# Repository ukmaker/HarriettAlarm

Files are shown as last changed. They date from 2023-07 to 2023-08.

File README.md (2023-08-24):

-- An STM32 BlackPill based alarm clock.

Called the Harriett clock because that's the name of my personal trainer.
Sometimes I forget to set the alarm on my phone or otherwise botch getting up.
This is embarrassing, rude and annoying :-(
So I invented the Harriett alarm so that it was obvious even to an old short-sighted
person like me what is happening the next day:

  * Picture of me tucked up in bed => I get to sleep in. No alarm set.
  * Picture of me with a phone to my ear => Work! Alarm!
  * Picture of me lifting weights with Harriett counting the reps(*) => Training day! Alarm!

(*) We always disagree on the number of reps I've done.

With added special features like
 * you can set the time (!)
 * each alarm can have a different tone and volume (!!)

Originally this was built to use a DFRobot MP3 player, and there was a selection of 
eight alarm tones to choose from. However the module consumes so much power at start-up
(and takes so long to start) that it was causing problems. So I replaced it with a simple
set of beeping tones using a Timer and PWM. The code (and the hardware design) for the MP3 
player is still in place however, should you wish to actually build this thing.

The rest of the hardware involves a Waveshare epaper screen, some buttons
and a 3D printed box.

In order to help with debugging I also embedded my Forth virtual machine, which communicates
over a serial port. This was surprisingly useful and not at all silly and done for the sake of it.
Honest.

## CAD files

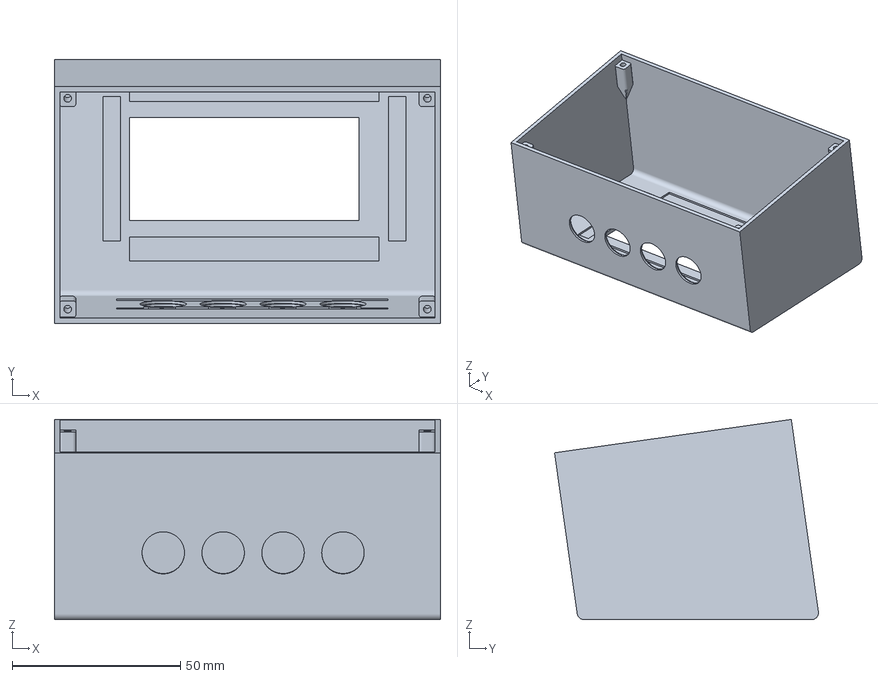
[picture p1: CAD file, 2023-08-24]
V1.0/OpenSCAD/HarriettBox2.3mf
114.6 x 78.4 x 59.4 mm

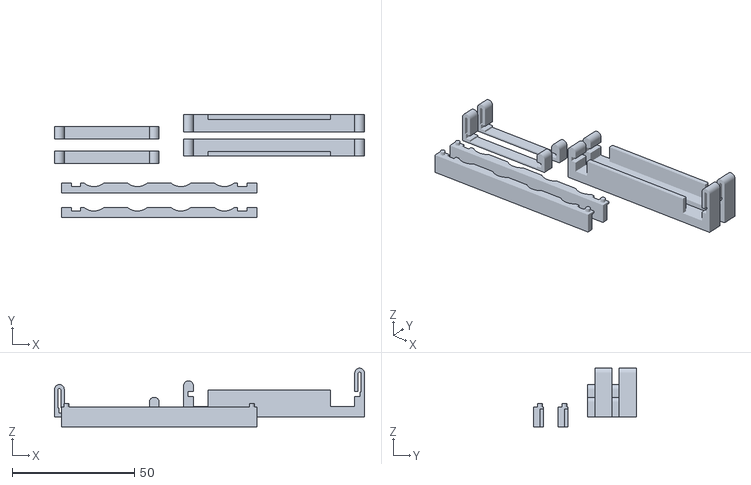
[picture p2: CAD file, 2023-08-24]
V1.0/OpenSCAD/HarriettBox2-Clips.stl
126.8 x 42.0 x 24.0

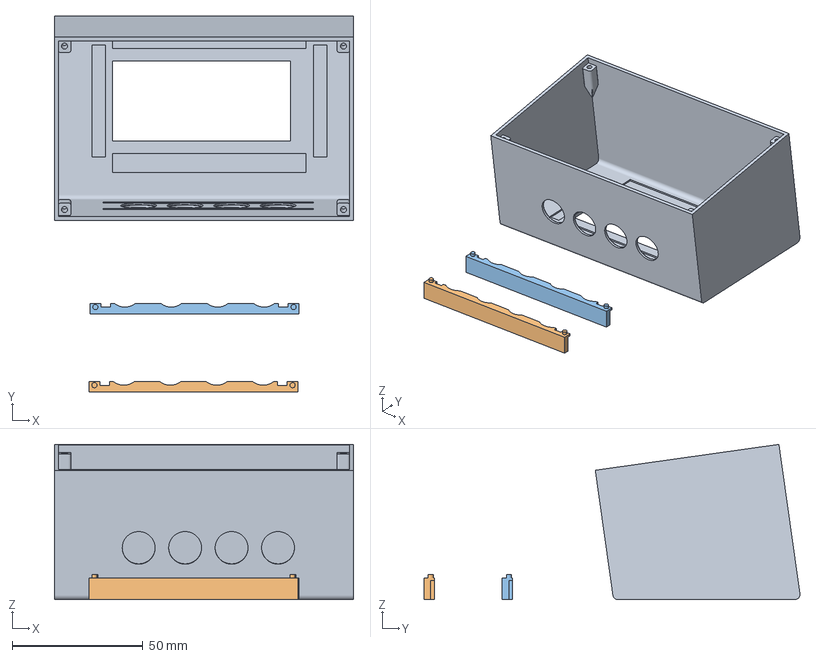
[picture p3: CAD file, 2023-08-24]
V1.0/OpenSCAD/HarriettBox2-PCBClips.3mf
114.6 x 143.9 x 59.4 mm
HarriettBox2.stl_1
HarriettBox2.stl_2
HarriettBox2.stl_3

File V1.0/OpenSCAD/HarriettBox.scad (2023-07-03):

use <ukmaker_openscad_lib/Generics.scad>
use <ukmaker_openscad_lib/Standoffs.scad>
use <ukmaker_openscad_lib/Batteries.scad>
use <ukmaker_openscad_lib/Waveshare.scad>
use <ukmaker_openscad_lib/Boxes.scad>
use <ukmaker_openscad_lib/Speakers.scad>
use <ukmaker_openscad_lib/GreenProtoBoards.scad>

include <NopSCADlib/utils/core/core.scad>


include <NopSCADlib/vitamins/buttons.scad>
include <NopSCADlib/vitamins/button.scad>

if($preview) {
    $fn=10;
    } else {
    $fn = 100;
    }





box_w = 110;

// box needs too be tall enough to hold a 4-cell aa battery box
box_h = 64;
box_d1 = 60;

// depth to allow for batteries
box_d2 = 80;

box_thickness = 1.4;
radius = 4;
base = box_d2 - box_d1;
theta = atan(box_h/base);

button_grid_spacing = 2.54 * 7;
// eink_panel_height = 37
// eink_panel_width = 79
display_offset_y = (box_h - 37) / 2;
display_offset_x = (box_w - 79) / 2 - 2.4;
eink_panel_width = 79;

module box_front() {
    difference() 
    {

        sloping_front_console(box_w,box_h,box_d1,box_d2,box_thickness,radius);

        // buttons centred in the box
        button_left = (box_w - (3 * button_grid_spacing)) / 2;

        translate([button_left,10,box_h-10]){
            translate([0,30,0])
            square_button(button_12mm, "yellow");

            translate([button_grid_spacing,30,0])
            square_button(button_12mm, "yellow");

            translate([2 * button_grid_spacing,30,0])
            square_button(button_12mm, "yellow");

            translate([3 * button_grid_spacing,30,0])
            square_button(button_12mm, "yellow");

        }

    
        rotate([theta,0,0])
        translate([display_offset_x,display_offset_y,-4])
        waveshare_2_9_epaper_cutout();
    }

    //rotate([theta,0,0])
    //    translate([display_offset_x,display_offset_y,-(1+2)])
    //    waveshare_2_9_epaper_standoffs();



    // add screw mountings for m3 screws
    translate([0,box_d2-2.5,0])
    rotate([90,0,0])
    op_4_grid(box_w, box_h, 4,4,4,4) {
        difference() {
            translate([-3,-3,0])
            cube([6,6,20]);
            translate([0,0,-.5])
            cylinder(h=21,d=2.5);
        }
    }
}

/*
// batteries
translate([70,45,3])
rotate([0,0,180])
aa_4_flat_battery_holder();

// speaker
translate([3,30,30])
rotate([0,90,0])
color("Silver")
speaker();
*/

module back_panel() {
    // back panel
    b_w = box_w - 2*box_thickness - 0.15;
    b_h = box_h - 2*box_thickness - 0.15;
    
    bh_left = (box_w - aa_4_flat_battery_holder_width()) / 2;
    bh_top = (box_h - aa_4_flat_battery_holder_height()) / 2;
    
    
    cube([b_w, b_h, box_thickness]);
    
    // battery pack mounting points
    translate([bh_left,bh_top,box_thickness - 0.15])
    aa_4_flat_battery_holder_mounting_holes(depth = 1.6, dia = 4.5);
}


module back_panel_piercings() {
    // back panel
    b_w = box_w - 2*box_thickness - 0.15;
    b_h = box_h - 2*box_thickness - 0.15;
    b_o = 4 - box_thickness;

    delta = box_thickness + 0.15/2;
    // screw holes
    op_4_grid(b_w, b_h, b_o, b_o, b_o, b_o)
    translate([0,0,-0.1])
    cylinder(h=2 * box_thickness, d = 2.5);
}

module place_back_panel() {
    // back panel
    b_w = box_w - 2*box_thickness - 0.15;
    b_h = box_h - 2*box_thickness - 0.15;
    b_o = 4 - box_thickness;

    translate([delta,box_d2,0])
   // rotate([90,0,0])
    color("grey")
    difference() {
        back_panel();
        back_panel_piercings();
    }
}

// mounting strips for the button proto-board
// this is a green proto 2cmx8cm
module proto_board_mounting_strip() {

    spacing_x = 73.9 + 2;
    spacing_y = 18.2 - 2;
    dy = 1.8;
    term_c = 5.5;
    term_s = 2.5;

    difference() {
        cube([80,4,8.2], center=true);
        
        translate([-36.1,1.3,-1])
        cube([8, 1.5,8.3], center = true);
        translate([36.1,1.3,-1])
        cube([8, 1.5,8.3], center = true);
        
        translate([-41.35 + term_c, 0.55, 2])
        cube([term_s*1.5, term_s, term_s]);
        translate([37.6 - term_c, 0.55, 2])
        cube([term_s*1.5, term_s, term_s]);
        
        translate([ - 1.5 * button_grid_spacing, 7,-4.2]) {
            
            translate([0,0,0])
            cylinder(h=9, d=12.8);
            
            translate([button_grid_spacing,0,0])
            cylinder(h=9, d=12.8);
            
            translate([2* button_grid_spacing,0,0])
            cylinder(h=9, d=12.8);
            
            translate([3 * button_grid_spacing,0,0])
            cylinder(h=9, d=12.8);
        }
    }
    
    translate([-spacing_x/2,.6,4-0.1])
    cylinder(h=1.6,d=2);
    translate([spacing_x/2,.6,4-0.1])
    cylinder(h=1.6,d=2);
}




module probe() {
    translate([0,6,0])
    cube([4,4,1.6]);
}



place_back_panel();
//proto_board_mounting_strip();
//translate([0,8,0])
//proto_board_mounting_strip();

module front() {
    difference() {

        box_front();
        eink_pcb_width = 89.6;
        rotate([theta,0,0])
        translate([display_offset_x,display_offset_y,-1]) {
            translate([eink_pcb_width-4.8,0,0])
            
            translate([0,41,0])
            rotate([180,0,0])
            pcb_mounting_clip(38.8, 1.6, 5.1, 1.6, 4);
            
            translate([0,41,0])
            rotate([180,0,0])    
            pcb_mounting_clip(38.8, 1.6, 5.1, 1.6, 4);

        }
    }
}

//probe();
front();
// for the display
//pcb_mounting_clip(38.5, 1.6, 5, 1.6, 4);
// for the main board
board_w = 70;
board_d = 50;
board_t = 1.6;
board_c = 7;

//pcb_mounting_clip(board_d, board_t+0.2, 5, board_c, 4);

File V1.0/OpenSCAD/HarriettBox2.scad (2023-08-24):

/**
* Improved box for the Harriet Alarm Clock
**/
use <ukmaker_openscad_lib/Generics.scad>
use <ukmaker_openscad_lib/Standoffs.scad>
use <ukmaker_openscad_lib/Batteries.scad>
use <ukmaker_openscad_lib/Waveshare.scad>
use <ukmaker_openscad_lib/Boxes.scad>
use <ukmaker_openscad_lib/Panels.scad>
use <ukmaker_openscad_lib/Screws.scad>
use <ukmaker_openscad_lib/Speakers.scad>
use <ukmaker_openscad_lib/GreenProtoBoards.scad>
use <ukmaker_openscad_lib/DevBoards.scad>

include <NopSCADlib/utils/core/core.scad>
include <NopSCADlib/vitamins/buttons.scad>
include <NopSCADlib/vitamins/button.scad>

$fn = 200;

epaper_to_main_board_spacing_z = 5;

width = waveshare_2_9_epaper_pcb_width() + 25;
height = 71;
depth_top = 50;
depth_bottom = 60;
thickness = 1.6;
rounding = 2;
box_lid_lip_height = 1.5;

button_grid_spacing = 2.54 * 7;
display_left = 5.5;
display_bottom = 25;

box_inner_width =  width - 2 * thickness;
box_inner_height =  height - 2 * thickness;

module connector() {
    h = 18;
    s = 2.7;
    color("Black")
    cube([s,s,h]);
}

module display() 
{
    // flip over
    translate([display_left,waveshare_2_9_epaper_height(),0])
    rotate([180,0,0])
    waveshare_2_9_epaper_module();
}

module display_cutout() {
    // flip over
    translate([display_left,waveshare_2_9_epaper_height(),0])
    rotate([180,0,0])
    waveshare_2_9_epaper_cutout();
}

module main_board() 
{
    proto_board_70_x_50();
    translate([15,1,2.6]) we_act_black_pill();
    // for fitting purposes
    translate([10,40,2.6])
    connector();
}
module board_stack()
{
    dx = (waveshare_2_9_epaper_width() - 70)/2 + display_left;
    dy = (waveshare_2_9_epaper_height() - 50) / 2;
    dz = epaper_to_main_board_spacing_z;
    display();
    
    translate([dx,dy,dz])  
    main_board();
}

module epaper_mounting_clip(margin=0) 
{
    pcb_mounting_clip(38.8+margin, 1.6, 5.1+margin, 1.6, 4);
}

module epaper_mounting_clips(margin=0) 
{
    epaper_mounting_clip(margin);

    translate([waveshare_2_9_epaper_pcb_width()-4.8,0,0])
    epaper_mounting_clip(margin);
}

module place_epaper_mounting_clips(margin=0) 
{
    translate([display_left-.1,-2.1,-3.5])
    epaper_mounting_clips(margin);
}

module main_board_mounting_clip(margin=0,left=true) 
{
    if(left) {
        translate([10,-2,0]) cube([50,2,11]);
    } else {
        translate([10,-7,0]) cube([50,2,11]);
    }
    rotate([0,0,-90])pcb_mounting_clip(70+margin, 1.6, 7+margin, 8.3, 4);
}

module main_board_mounting_clips(margin=0) 
{
    translate([display_left,-0.1,0])
    {
        main_board_mounting_clip(margin, false);
    }
    
    translate([display_left,50-2.8,0])
    {
        main_board_mounting_clip(margin);
    }
}

module place_main_board_mounting_clips(margin=0)
{
    translate([7.75,-0.8,-3.5])
    main_board_mounting_clips(margin);
}

module sized_mounting_pillar() {
    rotate([-90,0,0])
    blended_mounting_pillar(5,10,2.3,10);
}

module panel_mounting_pillars() {
        pillar_side = 5;
        pillar_height = 10;
        
        box_inner_height =  height - 2 * thickness;
        // mounting pillars at the corners
        x0 = thickness - 0.2 + pillar_side/2;
        z0 = thickness - 0.2 + pillar_side/2;
        x1 = width - thickness + 0.2 - pillar_side/2;
        dy = depth_bottom - thickness + 0.2 - pillar_height -box_lid_lip_height;
        z1 = thickness + box_inner_height  + 0.2 - pillar_side/2;
        translate([x0,dy,z0]) rotate([0,-90,0]) sized_mounting_pillar();
        translate([x0,dy,z1]) sized_mounting_pillar();
        translate([x1,dy,z1]) rotate([0,90,0]) sized_mounting_pillar();
        translate([x1,dy,z0]) rotate([0,180,0]) sized_mounting_pillar();
}

module mounting_hole_piercing() {
    translate([0,0,-8.99])
    countersunk_screw_M2(10);
}

module panel_mounting_holes_piercings() {
        pillar_side = 5;
        pillar_height = 10;
        
        // mounting pillars at the corners
        delta = 0.1;
        x0 = - delta + pillar_side/2;
        y0 = - delta + pillar_side/2;
        x1 = box_inner_width  - x0;
        y1 = box_inner_height - y0;
        dz = 1.2;
        translate([x0,y0,dz]) mounting_hole_piercing();
        translate([x0,y1,dz]) mounting_hole_piercing();
        translate([x1,y1,dz]) mounting_hole_piercing();
        translate([x1,y0,dz]) mounting_hole_piercing();
}

module box_body() {
    panel_mounting_pillars();
    sloping_front_console(width, height, depth_top, depth_bottom, thickness, rounding);
}

function theta() = asin(height/sqrt(height*height + (depth_bottom - depth_top) * (depth_bottom - depth_top)));

module place_on_front() {
    translate([ 9,12,50])
    rotate([-180+theta(),0,0])
    children();
}

module button_strip() {
    // buttons centred in the box
    button_left = (width - (3 * button_grid_spacing)) / 2;
    
    s = 1.05;
    translate([0,0,0])
    scale([s,s,1])
    square_button(button_12mm, "yellow");

    translate([button_grid_spacing,0,0])
    scale([s,s,1])
    square_button(button_12mm, "yellow");

    translate([2 * button_grid_spacing,0,0])
    scale([s,s,1])
    square_button(button_12mm, "yellow");

    translate([3 * button_grid_spacing,0,0])
    scale([s,s,1])
    square_button(button_12mm, "yellow");
}


// mounting strips for the button proto-board
// this is a green proto 2cmx8cm
module proto_board_mounting_strip(for_difference = false) {

    module button_mounting_strip() {
        spacing_x = 73.9 + 2;
        spacing_y = 18.2 - 2;
        dy = 1.8;
        term_c = 5.5;
        term_s = 2.5;

        difference() 
        {
            cube([80,4,8.2], center=true);
            
            translate([-36.1,1.3,-1])
            cube([8, 1.5,8.3], center = true);
            translate([36.1,1.3,-1])
            cube([8, 1.5,8.3], center = true);
            
            translate([-41.35 + term_c, 0.55, 2])
            cube([term_s*1.5, term_s, term_s]);
            translate([37.6 - term_c, 0.55, 2])
            cube([term_s*1.5, term_s, term_s]);
            
            translate([ - 1.5 * button_grid_spacing, 7,-4.2]) {
                
                translate([0,0,0])
                cylinder(h=9, d=12.8);
                
                translate([button_grid_spacing,0,0])
                cylinder(h=9, d=12.8);
                
                translate([2* button_grid_spacing,0,0])
                cylinder(h=9, d=12.8);
                
                translate([3 * button_grid_spacing,0,0])
               cylinder(h=9, d=12.8);
            }
        }
        
        translate([-spacing_x/2,.6,4-0.1])
        cylinder(h=1.6,d=2);
        translate([spacing_x/2,.6,4-0.1])
        cylinder(h=1.6,d=2);
    }
    
    if(for_difference) {
        scale([1.007, 1.007, 1.005])
        button_mounting_strip();
    } else {
        button_mounting_strip();
    }
}

module wiring_comb() {
    w = 45;
    l = 4;
    d = 3;
    color("White")
    cube([w,l,d]);
}

module button_assembly(for_difference=false) {

    translate([(width - (3 * button_grid_spacing)) / 2 - 1.7,8.5,4])
    {
        rotate([180,0,0])
        proto_board_mounting_strip(for_difference);
        translate([0,-17,0])
        rotate([180,0,180])
        proto_board_mounting_strip(for_difference);
    }
    translate([2.5,0,0])
    button_strip();
    translate([-11,-10,-1.5])
    {
        proto_board_80_x_20();
        translate([0,8,-3])
        wiring_comb();
    }
}

module back_panel(component)
{
    holder_w = 50;
    holder_d = 53;
    holder_h = 13;
    
   difference() 
    {
        panel_with_recess_and_screw_cover_components(
            component, 
            box_inner_width-0.1,box_inner_height-0.1,3,0.1,  
            holder_w,holder_d,holder_h,2,1.5,  
            1.5, 
            5,8, 
            5, 
            2);
        if(component == Panel_Component_Recess()) {
            // drill a hole for the battery wires
            translate([holder_w - 5, holder_d + 6, -holder_h-3])
            cylinder(h=4, d=4);
        }
        
        if(component == Panel_Component_Panel()) {        
            panel_mounting_holes_piercings();
            translate([85.5,35,0.2])
            color("Silver")
            rotate([180,00])
            {
                scale([1.005,1.005,1])
                speaker_round_50mm();
                translate([0,0,-4])
                grille_speaker_round_50mm(2,5);
            }
        }
    }

}

module button_placement_marks()
{
    translate([20,30,height])
    color("Red") cube([2,10,2]);
    translate([width - 22,30,height])
    color("Red") cube([2,10,2]);
}

module place_button_assembly(for_difference = false) {
    translate([display_left+24.3,30,height-9.2])
    button_assembly(for_difference);
}
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

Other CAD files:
V1.0/OpenSCAD/HarriettBox2-Panel.3mf
V1.0/OpenSCAD/HarriettBox2-Panel.stl
V1.0/OpenSCAD/HarriettBox2.stl

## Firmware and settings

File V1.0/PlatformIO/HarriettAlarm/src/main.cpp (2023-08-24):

/**
 * The Harriett Alarm Clock
 * Optionally, also runs Forth
*/
//#define HARRIETT_GOES_FORTH

#include "Buttons.h"
#include "View.h"
#include "epaper.h"
#include "lesson.h"
#include "sleep_in.h"
#include "work.h"

#include "Alarm.h"
#include "WavetableAlarm.h"

#include "STM32LowPower.h"
#include "TimerInterrupt_Generic.h"

#include <Arduino.h>
#include <STM32RTC.h>
#include <ctype.h>
#include <stdio.h>
#include <stdlib.h>
#include <unistd.h>

#ifdef HARRIETT_GOES_FORTH
    #include "ForthConfiguration.h"
    #include "ForthVM.h"
    #include "STM32Dev.h"
    #include "UnsafeMemory.h"
    #include "local_syscalls.h"
    #include "syscalls.h"
#endif

#define TICK_MS 10

STM32Timer debounceTimer(TIM2);
HardwareTimer pwm;

int ticks = 0;

void startAlarm();
void stopAlarm();
void snoozeAlarm();

STM32RTC& rtc = STM32RTC::getInstance();

uint8_t setMode, lastSetMode;
uint8_t alarmState;
bool settingVolume = 0;

bool mp3Enabled = 0;

time_t now;

Alarm workAlarm(7, 0, 1, 10, work_bitmap, work_width, work_height);
Alarm lessonAlarm(12, 2, 2, 10, lesson_bitmap, lesson_width, lesson_height);
Alarm* activeAlarm = NULL;
Bitmap sleepInBitmap(sleep_in_bitmap, sleep_in_width, sleep_in_height);
ClockTime clockTime(12, 0);

View view(display);

WavetableAlarm wavAlarm;

#define SET_MODE_IDLE 0
#define SET_MODE_TIME 1
#define SET_MODE_ALARM_TIME 2
#define SET_MODE_ALARM_TONE 3

#define BY_ONE 0
#define BY_FIVE 1

#define LESSON_BUTTON_PIN PB7
#define WORK_BUTTON_PIN PB6
#define SNOOZE_HH_BUTTON_PIN PB8
#define STOP_MM_BUTTON_PIN PB9

volatile bool alarmInterrupt = 1;

#define ALARM_STATE_IDLE 0
#define ALARM_STATE_STARTING 1
#define ALARM_STATE_SOUNDING 2
#define ALARM_STATE_SNOOZING 3

#define ALARM_SNOOZE_MINUTES 10

#define HOST_RX PA10

time_t snoozeEpoch;

Buttons buttons(LESSON_BUTTON_PIN,
    WORK_BUTTON_PIN,
    SNOOZE_HH_BUTTON_PIN,
    STOP_MM_BUTTON_PIN);



time_t expiry;
volatile bool active;
volatile bool buttonEvent;
volatile bool serialIn;
volatile bool updateTick;

/***************************************************
 * Interrupt handlers
 ***************************************************/
void debounceInterruptHandler()
{
    static unsigned int milliseconds = 0;
    milliseconds += TICK_MS;
    buttons.update(milliseconds);
}

void alarmMatch(void* data)
{
    alarmInterrupt = true;
}

void buttonCallback()
{
    buttonEvent = true;
}

void minuteTick(void* data)
{
    updateTick = true;
}

void serialInput()
{
    serialIn = true;
}

void pwmInterruptHandler(void)
{
    TIM1->CCR1 = wavAlarm.nextSample();
}

/***************************************************
 * Manage the PWM for generating sounds
****************************************************/
void startPWM() {
   pwm.resume();
}

void stopPWM() {
    pwm.pause();
}

void initPWM() {
    pwm.setup(TIM1);
    pwm.setPWM(1, PA8, 48000, 50, pwmInterruptHandler);
}

void stopSound() {
    pwm.pause();
}

void startSound() {
    startPWM();
}

void initSound() {
    initPWM();
}

void playSound() {
    wavAlarm.start(activeAlarm->tone(), activeAlarm->volume());
    startSound();
}

/***************************************************
 * Set time and alarm
 ***************************************************/
void activateSleepIn()
{
    view.setBitmap(sleepInBitmap);
    view.clearAlarmTime();
    view.clearSetAlarmTime();
    rtc.disableAlarm(STM32RTC::Alarm::ALARM_B);
    activeAlarm = NULL;
    setMode = SET_MODE_IDLE;
}

void updateAlarmTime(Alarm* alarm)
{
    rtc.setAlarmDay(1, STM32RTC::Alarm::ALARM_B);
    rtc.setAlarmHours(alarm->time().h(), STM32RTC::Alarm::ALARM_B);
    rtc.setAlarmMinutes(alarm->time().m(), STM32RTC::Alarm::ALARM_B);
    rtc.setAlarmSeconds(5, STM32RTC::Alarm::ALARM_B);
    rtc.enableAlarm(STM32RTC::MATCH_HHMMSS, STM32RTC::Alarm::ALARM_B);
    activeAlarm = alarm;
}

void setActiveAlarm(Alarm* alarm)
{
    view.setBitmap(alarm->bitmap());
    view.clearSetAlarmTime();
    view.displayAlarmTime(alarm);
    view.clearAlarmSnoozing();
    updateAlarmTime(alarm);
    setMode = SET_MODE_IDLE;
}

void activateWorkAlarm()
{
    setActiveAlarm(&workAlarm);
}

void activateLessonAlarm()
{
    setActiveAlarm(&lessonAlarm);
}

void setModeIdle()
{
    setMode = SET_MODE_IDLE;
    view.updateClock(clockTime);
    view.clearSetTime();
    view.clearSetAlarmTime();
    view.clearSetAlarmTone();
    stopSound();
}

void setModeSetTime()
{
    setMode = SET_MODE_TIME;
    view.updateClock(clockTime);
    view.clearSetAlarmTime();
    view.clearSetAlarmTone();
    view.showSetTime();
}

void setModeSetWorkAlarmTime()
{
    activateWorkAlarm();
    setMode = SET_MODE_ALARM_TIME;
    view.showSetAlarmTime();
}

void setModeSetLessonAlarmTime()
{
    activateLessonAlarm();
    setMode = SET_MODE_ALARM_TIME;
    view.showSetAlarmTime();
}

void setModeSetWorkAlarmTone()
{
    activateWorkAlarm();
    setMode = SET_MODE_ALARM_TONE;
    view.showSetAlarmTone();
}

void setModeSetLessonAlarmTone()
{
    activateLessonAlarm();
    setMode = SET_MODE_ALARM_TONE;
    view.showSetAlarmTone();
}

void bumpAlarmVolume(bool up)
{
    startSound();
    if (up) {
        activeAlarm->louder();
    } else {
        activeAlarm->quieter();
    }
    //mp3Alarm.play(activeAlarm->tone(), activeAlarm->volume());
    wavAlarm.start(activeAlarm->tone(), activeAlarm->volume());
    view.displayAlarmTime(activeAlarm);
}

void bumpTimeOrTone(bool hours, bool byFive) {
    // If we're setting the time then bump the hours
    switch (setMode) {
    case SET_MODE_TIME:
        clockTime.getRTC();
        if(hours) {
            clockTime.incrementHours(byFive);
        } else {
            clockTime.incrementMinutes(byFive);
        }
        clockTime.setRTC();
        view.updateClock(clockTime);

        break;

    case SET_MODE_ALARM_TIME:
        if(hours) {
            activeAlarm->time().incrementHours(byFive);
        } else {
            activeAlarm->time().incrementMinutes(byFive);
        }
        updateAlarmTime(activeAlarm);
        view.displayAlarmTime(activeAlarm);
        break;

    case SET_MODE_ALARM_TONE:

        if (activeAlarm != NULL) {
            if(hours) {
                activeAlarm->nextTone();
            } else {
                activeAlarm->prevTone();
            }
            view.displayAlarmTime(activeAlarm);
            playSound();
        }

        break;

    default:
        break;
    }
}

/***************************************************
 * Click handlers b2 b1 b3 b4
 ***************************************************/
void b1ClickHandler()
{
    if (alarmState == ALARM_STATE_SOUNDING) {
        snoozeAlarm();
    } else if (setMode == SET_MODE_ALARM_TONE) {
        bumpAlarmVolume(false);
    }
}

void b2ClickHandler()
{
    if (alarmState == ALARM_STATE_SOUNDING) {
        snoozeAlarm();
    } else if (setMode == SET_MODE_ALARM_TONE) {
        bumpAlarmVolume(true);
    }
}

void b1LongClickHandler(void)
{
    if (setMode != SET_MODE_ALARM_TONE && setMode != SET_MODE_TIME) {
        if (activeAlarm != NULL) {
            activateSleepIn();
        } else {
            activateWorkAlarm();
        }
    }
}

void b2LongClickHandler(void)
{
    if (setMode != SET_MODE_ALARM_TONE && setMode != SET_MODE_TIME) {
        if (activeAlarm != NULL) {
            activateSleepIn();
        } else {
            activateLessonAlarm();
        }
    }
}
/**
 * Long presses on both right buttons cycle through the settings
 * - If no alarm is active just activate or deactivate setting the time
 * - If an alarm is active cycle between setting the alarm time, alarm sound or nothing
 **/
void b1b2LongClickHandler(void)
{
    switch (setMode) {

    case SET_MODE_ALARM_TIME:
        setMode = SET_MODE_ALARM_TONE;
        view.clearSetAlarmTime();
        view.showSetAlarmTone();
        break;

    case SET_MODE_ALARM_TONE:
        setMode = SET_MODE_IDLE;
        view.clearSetAlarmTone();
        stopSound();
        break;

    case SET_MODE_IDLE:
    default:
        setMode = SET_MODE_ALARM_TIME;
        view.showSetAlarmTime();
        break;
    }
}

void b3ClickHandler(void)
{
    if (alarmState == ALARM_STATE_SOUNDING) {
        snoozeAlarm();
    } else {
        bumpTimeOrTone(true, false);
    }
}

void b4ClickHandler(void)
{
    if (alarmState == ALARM_STATE_SOUNDING || alarmState == ALARM_STATE_SNOOZING) {
        stopAlarm();
    } else {
        bumpTimeOrTone(false, false);
    }
}

void b3b4LongClickHandler()
{
    if (setMode == SET_MODE_TIME) {
        setModeIdle();
    } else {
        setModeSetTime();
    }
}

void b3RepeatClickHandler(void)
{
    bumpTimeOrTone(true, true);
}

void b4RepeatClickHandler(void)
{
    bumpTimeOrTone(false, true);
}

/***************************************
 * Timer triggered actions
****************************************/
void soundAlarm()
{
    alarmState = ALARM_STATE_SOUNDING;
    playSound();
    view.clearAlarmSnoozing();
}

void stopAlarm()
{
    alarmState = ALARM_STATE_IDLE;
    rtc.disableAlarm(STM32RTC::Alarm::ALARM_B);
    stopSound();
    view.clearAlarmSnoozing();
}

void snoozeAlarm()
{
    time_t epoc = rtc.getEpoch();
    alarmState = ALARM_STATE_SNOOZING;
    snoozeEpoch = epoc + 60 * ALARM_SNOOZE_MINUTES;
    rtc.setAlarmEpoch(snoozeEpoch, STM32RTC::Alarm_Match::MATCH_HHMMSS, STM32RTC::Alarm::ALARM_B);
    stopSound();
    view.showAlarmSnoozing(snoozeEpoch, epoc, 60 * ALARM_SNOOZE_MINUTES);
}

void sleepClock()
{
    //Serial.println("Sleeping");
    stopSound();
    digitalWrite(LED_BUILTIN, HIGH);
    display.hibernate();
    //Serial.end();
    pinMode(HOST_RX, INPUT_PULLUP);
    LowPower.attachInterruptWakeup(HOST_RX, serialInput, FALLING);
    HAL_SuspendTick();
    LowPower.deepSleep(60000);
    HAL_ResumeTick();
    //Serial.begin(115200);
    //Serial.println("Resume");
    digitalWrite(LED_BUILTIN, LOW);
}

/************************************************************************
 * Forth for fun and fancy
 ************************************************************************/
#ifdef HARRIETT_GOES_FORTH

uint8_t ram[8192];

UnsafeMemory mem(ram, 8192, 0x2000, rom, 8192, 0);

Syscall syscalls[40];

ForthVM vm(&mem, syscalls, 40);

void syscall_debug(ForthVM* vm)
{
    uint16_t action = vm->pop();
    uint8_t v;
    activeAlarm = &workAlarm;
    switch (action) {
    case 1:
        soundAlarm();
        break;
    case 2:
        stopAlarm();
        break;
    case 3:
        snoozeAlarm();
        break;
    case 4:
        startSound();
        break;
    case 5:
        stopSound();
        break;
    case 6: {
        vm->push(active);
        vm->push(alarmState);
        vm->push(now);
        vm->push(expiry);
        vm->push(snoozeEpoch);
        break;
    }
    case 7:
        sleepClock();
        break;
    case 8:
        activeAlarm->louder();
        playSound();
        break;
    case 9:
        activeAlarm->quieter();
        playSound();
        break;
    case 10:
        v = vm->pop();
        v += 2;
        activeAlarm->setVolume(v);
        playSound();
    case 11:
        v = activeAlarm->volume();
        vm->push(v);
    default:
        break;
    }
}

void attachSyscalls()
{
    vm.addSyscall(SYSCALL_DEBUG, syscall_debug);
    vm.addSyscall(SYSCALL_TYPE, syscall_type);
    vm.addSyscall(SYSCALL_TYPELN, syscall_typeln);
    vm.addSyscall(SYSCALL_DOT, syscall_dot);
    vm.addSyscall(SYSCALL_GETC, syscall_getc);
    vm.addSyscall(SYSCALL_PUTC, syscall_putc);
    vm.addSyscall(SYSCALL_INLINE, syscall_inline);
    vm.addSyscall(SYSCALL_FLUSH, syscall_flush);
    vm.addSyscall(SYSCALL_NUMBER, syscall_number);
    vm.addSyscall(SYSCALL_H_AT, syscall_read_host);
    vm.addSyscall(SYSCALL_H_STORE, syscall_write_host);
    vm.addSyscall(SYSCALL_D_ADD, syscall_add_double);
    vm.addSyscall(SYSCALL_D_SUB, syscall_sub_double);
    vm.addSyscall(SYSCALL_D_DIV, syscall_mul_double);
    vm.addSyscall(SYSCALL_D_MUL, syscall_div_double);

    vm.addSyscall(SYSCALL_D_SR, syscall_sr_double);
    vm.addSyscall(SYSCALL_D_SL, syscall_sl_double);
    vm.addSyscall(SYSCALL_D_AND, syscall_and_double);
    vm.addSyscall(SYSCALL_D_OR, syscall_or_double);

    vm.addSyscall(SYSCALL_DOTC, syscall_dot_c);

    vm.addSyscall(SYSCALL_FCLOSE, syscall_fclose);
    vm.addSyscall(SYSCALL_FOPEN, syscall_fopen);
    vm.addSyscall(SYSCALL_FREAD, syscall_fread);
}

char* source_code = "\
  : START 1 BREAKPOINT ; \n \
  : STOP 2 BREAKPOINT ; \n \
  : SNOOZE 3 BREAKPOINT ; \n \
  : ON 4 BREAKPOINT ; \n \
  : OFF 5 BREAKPOINT ; \n \
  : Q 6 BREAKPOINT \n \
    .\" SNOOZE \" . CRET \n \
    .\" EXPIRY \" . CRET \n \
    .\" NOW    \" . CRET \n \
    .\" STATE  \" . CRET \n \
    .\" ACTIVE \" . CRET ; \n \
  : SLEEP 7 BREAKPOINT ; \n \
  : +V 8 BREAKPOINT ; \n \
  : -V 9 BREAKPOINT ; \n \
  : V! 10 BREAKPOINT ; \n \
  : V@ 11 BREAKPOINT ; \n \
  \
";

#endif 

/***************************************
 * Initialisation
****************************************/
void setupRTC()
{
    rtc.setClockSource(STM32RTC::LSE_CLOCK);
    rtc.setPrediv(127, 255);
    rtc.begin();
    rtc.setTime(12, 0, 0);
    rtc.setDate(1, 1, 1, 2023);
    clockTime.getRTC();

    pinMode(LED_BUILTIN, OUTPUT);

    // Configure low power
    LowPower.begin();
}

void setupButtonInterrupts()
{
    LowPower.attachInterruptWakeup(LESSON_BUTTON_PIN, buttonCallback, FALLING, SLEEP_MODE);
    LowPower.attachInterruptWakeup(WORK_BUTTON_PIN, buttonCallback, FALLING, SLEEP_MODE);
    LowPower.attachInterruptWakeup(SNOOZE_HH_BUTTON_PIN, buttonCallback, FALLING, SLEEP_MODE);
    LowPower.attachInterruptWakeup(STOP_MM_BUTTON_PIN, buttonCallback, FALLING, SLEEP_MODE);
}

void attachEventHandlers()
{
    buttons.setB1ClickHandler(b1ClickHandler);
    buttons.setB2ClickHandler(b2ClickHandler);
    buttons.setB1LongClickHandler(b1LongClickHandler);
    buttons.setB2LongClickHandler(b2LongClickHandler);
    buttons.setB1B2LongClickHandler(b1b2LongClickHandler);

    buttons.setB3ClickHandler(b3ClickHandler);
    buttons.setB4ClickHandler(b4ClickHandler);
    buttons.setB3B4LongClickHandler(b3b4LongClickHandler);
    buttons.setB3RepeatClickHandler(b3RepeatClickHandler);
    buttons.setB4RepeatClickHandler(b4RepeatClickHandler);
}

void setup()
{

    setupRTC();
    view.setup();
    view.updateClock(clockTime);
    view.clearAlarmSnoozing();
    setMode = SET_MODE_IDLE;
    alarmState = ALARM_STATE_IDLE;
    activeAlarm = NULL;
    alarmInterrupt = false;
    buttonEvent = false;
    active = true;
    expiry = 0;
    serialIn = true;

    /**
     * Set up interrupts.
     * Use AlarmA for the actual clock's alarm
     * Use the wakeup timer to wake the clock every 60 seconds to
     * update the time
     *
     * Button interrupt handler used for setting time, alarms etc
     *
     * During sleep mode, disable UART1 and set its Rx pin to
     * be an input. This is then used to wakeup the CPU if its
     * state changes, at which point UART1 is re-enabled
     */
    rtc.attachInterrupt(alarmMatch, NULL, STM32RTC::Alarm::ALARM_B);
    setupButtonInterrupts();
    attachEventHandlers();

    rtc.setAlarmDay(1);
    rtc.setAlarmHours(0);
    rtc.setAlarmMinutes(0);
    rtc.setAlarmSeconds(60);
    rtc.enableAlarm(STM32RTC::MATCH_SS);
    rtc.attachInterrupt(minuteTick);

    pinMode(LED_BUILTIN, OUTPUT);
    digitalWrite(LED_BUILTIN, 1);
    #ifdef HARRIETT_GOES_FORTH
        attachSyscalls();
        Serial.begin(115200); // Forth communications with the host
        vm.reset();
    #endif
    debounceTimer.attachInterruptInterval(TICK_MS * 1000, debounceInterruptHandler);
    initSound();
}

void loop()
{
    //if (!buttonEvent)
    #ifdef HARRIETT_GOES_FORTH
        vm.step();
    #endif
    
    buttonEvent = false;

    uint32_t ms, secs;
    now = rtc.getEpoch(&ms);
    secs = now * 1000 + ms;

    buttons.dispatchEvents();
    active = buttons.active();

    // Now update the time - does a complete refresh every 60 seconds
    if (updateTick) {
        updateTick = false;
        clockTime.getRTC();
        view.updateClock(clockTime);

        if (alarmState == ALARM_STATE_SNOOZING) {
            // update the snooze progress bar
            view.showAlarmSnoozing(snoozeEpoch, now, 60 * ALARM_SNOOZE_MINUTES);
        }
    }

    // did an alarm go off?
    if (alarmInterrupt) {
        alarmInterrupt = 0;
        soundAlarm();
    }

    if (alarmState == ALARM_STATE_SOUNDING) {
        active = true;
    }

    if (active || serialIn) {
        active = false;
        serialIn = false;
        expiry = rtc.getEpoch() + 10;
    } else if (rtc.getEpoch() > expiry) {
        if (setMode != SET_MODE_IDLE) {
            setModeIdle();
        }
        buttons.reset();
        sleepClock();
    }
}

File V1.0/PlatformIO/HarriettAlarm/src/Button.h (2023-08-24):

#ifndef UKMAKER_BUTTON_H
#define UKMAKER_BUTTON_H

#include <Arduino.h>

#define B_IDLE 0
#define B_FALLEN 1
#define B_LOW 2
#define B_LONG_PRESSED 3
#define B_LONG_LOW 4
#define B_NOISY 5


#define DEBOUNCE_TIME 100
#define LONG_PRESS_TIME 1000
#define REPEAT_DELAY 1000
#define REPEAT_CADENCE 500

class Button {

public:

  Button(uint32_t pin)
    : _pin(pin) {
    pinMode(pin, INPUT_PULLUP);
  }

  ~Button() {}

  void update(uint32_t millis) {

    uint32_t now = millis;
    bool current_s;

    _repeating = 0;

    current_s = digitalRead(_pin);

    if (_pin_state != current_s) {
      // pin state has changed, reset the debounce counter
      _time = now;
      _state = B_NOISY;
      _pin_state = current_s;
      _next = now + LONG_PRESS_TIME + REPEAT_DELAY;
      return;
    }

    if(current_s) {
      // Pin is high 
      _state = B_IDLE;
      return;
    }

    // at this point we know the pin has gone low
    if(now > (_time + DEBOUNCE_TIME)) {
      // have we already issued a falling event?
      if(_state == B_NOISY) {
        _state = B_FALLEN;
        _clicked = true;
        _clicks++;
      } else if(_state == B_FALLEN) {
        _state = B_LOW;
      }
    }

    if(now > (_time + LONG_PRESS_TIME)) {
      if(_state == B_LOW) {
        _state = B_LONG_PRESSED;
      } else { 
        _state = B_LONG_LOW;
      }
      _repeating = 0;
    }

    if(_state == B_LONG_LOW && now > _next) {
      _repeating = 1;
      _next = now + REPEAT_CADENCE;
    }
  }

  bool isRepeating() {
    return _repeating;
  }

  bool isPressed() {
    return _state == B_LOW || _state == B_FALLEN;
  }

  bool isClicked() {
    //return _state == B_FALLEN;
    //return _clicked &&
    return _clicks > 0;
  }

  bool isLongPressed() {
    return _state == B_LONG_PRESSED || _state == B_LONG_LOW;
  }

  bool isLongClicked() {
    return _state == B_LONG_PRESSED;
  }

  bool isActive() {
    return !isNotActive();
  }

  bool isNotActive() {
    return _state == B_IDLE && _clicks == 0;
  }

  void handled() {
   //_clicked = false;
    if(_clicks > 0) _clicks--;
  }

  void reset() {
    _clicks = 0;
    _state = B_IDLE;
  }


protected:

  uint32_t _pin;
  uint32_t _time = 0;       // for debouncing
  uint32_t _next;           // time at which the next repeat will be signalled
  uint8_t _state = B_IDLE;  // has the button been processed
  bool _pin_state = 1;
  bool _repeating = 0;
  bool _clicked = false;
  uint8_t _clicks = 0;           // Tot up the clicks
};

#endif

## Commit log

2023-03-28 Initial import
    [Harriett.kicad_pcb, Harriett.kicad_sch]
2023-08-01 Various updates backported from EDAWin - may be broken
    [Harriett.kicad_sch, HarriettBox2-Clips.stl, HarriettBox2.3mf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]
2023-08-24 Updated 3D design. Latest code with PIO dependencies
    [HarriettBox2-Clips.stl, HarriettBox2-PCBClips.3mf, HarriettBox2-Panel.3mf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]
2023-08-24 Removed Arduino directory
2023-08-24 Removed old Cura files. Updated schematic for PWM option
    [Harriett.kicad_sch, HarriettBox-Back-Proto6.stl, HarriettBox-DisplayStrip-Proto7.stl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]
